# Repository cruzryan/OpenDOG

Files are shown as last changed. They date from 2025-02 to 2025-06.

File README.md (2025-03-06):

# OpenDOG

Low cost quadruped robot with SDK and Mujoco simulations, trained with Reinforcement Learning and fully opensource



## Features

- Fully 3D printed structure
- Mujoco simulation
- Trained using reinforcement learning
- Includes SDK to interface with the robot
- L515 custom SLAM implementation

## Authors

- Ryan Nathanael Cruz Barragan [@ryancruzb](https://www.github.com/ryancruzb)
- Mauricio Emiliano Ruiz Alamilla [@MaudorElConquistador](https://www.github.com/MaudorElConquistador)

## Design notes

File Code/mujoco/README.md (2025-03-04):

# 

Usage: python -m train.train [locomotion] --eval_frecuency m --n_envs n --seed i

python test [locomotion]

install.sh and upload_files.sh are scrpits for training in cloud, only tested with Azure

# Imporatant variables

## Access to information in mujoco

Information of the principal body: 

data.qvel = \[v_{x}, v_{y}, v_{z}, 
			\omega_{x}, \omega{y}, \omega{z},
			\dot{\theta_{1}}, \dot{\theta_{2}}, ...
			\dot{\theta_{n}} \]

data.qpos = \[x, y, z, 
			w, x, y, z,
			\theta_{1}, \theta_{2}, ...
			\theta_{n} \]

data.ncon = contacts number

mujoco._functions.mj_contactForce() this function get the force of a contact according to the order of appearance

Project structure 

1. debug_scene contains scripts that help to build the kinematic tree of the robot
2. environments contains a custom environments for each locomotion (maybe OOP inherence could help), this is the same for reward calculation.
3. wireless_communication is the viewer of python biding with a server udp and a client. For the moment it's only half-duplex communication
4. models are the neural networks trained for the specific locomotion.

├── best_model
│   └── best_model.zip
├── debug_scene
│   ├── Debug.py
│   ├── get_rotations.py
│   └── show_scene.py
├── environments
│   ├── jump_environment.py
│   ├── landing_environment.py
│   └── walk_environment.py
├── install.sh
├── logs
├── models
│   ├── jump
│   └── walk
├── our_robot
├── ppo_robot_tensorboard
├── README.md
├── rewards
│   ├── jump_environment_reward_calc.py
│   ├── landing_environment_reward_calc.py
│   └── walk_environment_reward_calc.py
├── test.py
├── train
│   ├── CurstomNetwork.py
│   ├── RobotUtilities.py
│   ├── train.py
│   └── VideoRecorder.py
├── unitree_go1/
├── upload_files.sh
├── videos
│   ├── jump
│   └── walk
├── viewer.py
└── wireless_comunication
    ├── client.py
    └── server.py

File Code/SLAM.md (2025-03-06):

# RealSense L515 SLAM with ROS Noetic on Ubuntu 20.04  

The realsense L515 camera was deprecated, and is not compatible with new librealsense updates or even realsense-viewer, this is a tutorial on how to do SLAM with the Intel L515 camera in 2025 lol

1. Install Ubuntu 20.04, downgrade kernel to 5.4 

	`sudo apt update`
 `sudo apt install linux-generic`

	Verify it’s there:

	`dpkg --list | grep linux-image`

	You should see linux-image-5.4.0-208-generic (or similar) alongside 5.15.

	`sudo reboot`

Note: When GRUB starts make sure to pick GRUB > “Advanced options” > pick 5.4 
`uname -r` should say 5.4.0-xx.

3.  Install dependencies:
    
    `sudo apt install -y git cmake libssl-dev libusb-1.0-0-dev libudev-dev pkg-config libgtk-3-dev libglfw3-dev libgl1-mesa-dev libglu1-mesa-dev`
    
4.  Clone and checkout v2.50.0:
    This is the latest realsense lib update that is compatible with L515
    `cd ~/Downloads git clone https://github.com/IntelRealSense/librealsense.git cd librealsense git checkout v2.50.0`
    
5.  Build and install (avoid libusb if on 5.4):
    
    `mkdir build && cd build cmake .. -DBUILD_EXAMPLES=true -DCMAKE_BUILD_TYPE=Release make -j4 && sudo make install`
    
    -   If USB errors (control_transfer), try `-DFORCE_RSUSB_BACKEND=true` instead, but 5.4 kernel driver worked for us.
6.  Test:
    
    `realsense-viewer`
    
## Step 3: Install ROS Noetic

Ubuntu 20.04 loves Noetic—our SLAM backbone.

1.  Setup repo:

    `sudo sh -c 'echo "deb http://packages.ros.org/ros/ubuntu focal main" > /etc/apt/sources.list.d/ros-latest.list'  sudo apt-key adv --keyserver 'hkp://keyserver.ubuntu.com:80' --recv-key C1CF6E31E6BADE8868B172B4F42ED6FBAB17C654`

	` sudo apt update`
    
2.  Install:

    `sudo apt install -y ros-noetic-desktop-full echo  "source /opt/ros/noetic/setup.bash" >> ~/.bashrc` 
    
    `source ~/.bashrc` 
    `sudo apt install -y python3-rosdep python3-rosinstall` 
    
    `sudo rosdep init rosdep update`

## Step 4: Install RealSense ROS Wrapper

Version 2.3.2 matches librealsense v2.50.0.

1.  Create workspace:
  
    `mkdir -p ~/catkin_ws/src`
    `cd ~/catkin_ws/src`
    `git clone -b 2.3.2 https://github.com/IntelRealSense/realsense-ros.git`
    
2.  Install dependency (our ddynamic_reconfigure snag):

    `sudo apt install -y ros-noetic-ddynamic-reconfigure`
    
3.  Build:

    `cd ~/catkin_ws` 
    `catkin_make source devel/setup.bash`
    `echo  "source ~/catkin_ws/devel/setup.bash" >> ~/.bashrc`

## Step 5: Install RTAB-Map

RTAB-Map’s our SLAM engine—needs core libs too.

1.  Install:
    
    `sudo apt install -y ros-noetic-rtabmap ros-noetic-rtabmap-ros`
    ` sudo ldconfig`

## Step 6: Run SLAM

Here’s the winning combo—two commands that finally worked after resolution hell.

### Command 1: Launch RealSense Camera

Set both RGB and depth to 640x480 (4:3 aspect ratio) to avoid rgbd_odometry crashes:

`roslaunch realsense2_camera rs_camera.launch \ enable_pointcloud:=true \ enable_color:=true \ enable_depth:=true \ color_width:=640 \ color_height:=480 \ color_fps:=30 \ depth_width:=640 \ depth_height:=480 \ depth_fps:=30`

-   Terminal 1—keep it running.

### Command 2: Launch RTAB-Map SLAM

Hook RTAB-Map to the camera:

`roslaunch rtabmap_ros rtabmap.launch \ rgb_topic:=/camera/color/image_raw \ depth_topic:=/camera/depth/image_rect_raw \ camera_info_topic:=/camera/color/camera_info \ args:="-d" \ rviz:=true \ rtabmapviz:=false`

-   Terminal 2—fires up SLAM and RViz.

## RViz Setup

-   **Fixed Frame**: camera_link
-   **Displays**:
    -   Map > /rtabmap/cloud_map (the SLAM map)
    -   Image > /camera/color/image_raw (RGB feed)
    -   PointCloud2 > /camera/depth/color/points (raw points)
    -   Odometry > /rtabmap/odom (pose)
-   Move the L515—map builds in real-time!

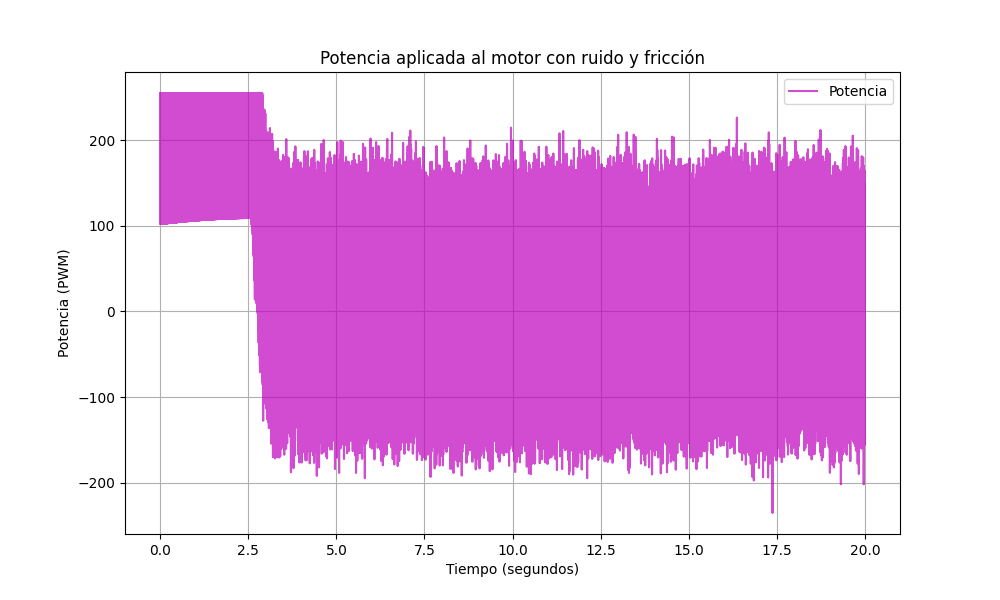
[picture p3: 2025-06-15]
Code/examples/potencia_pid.png

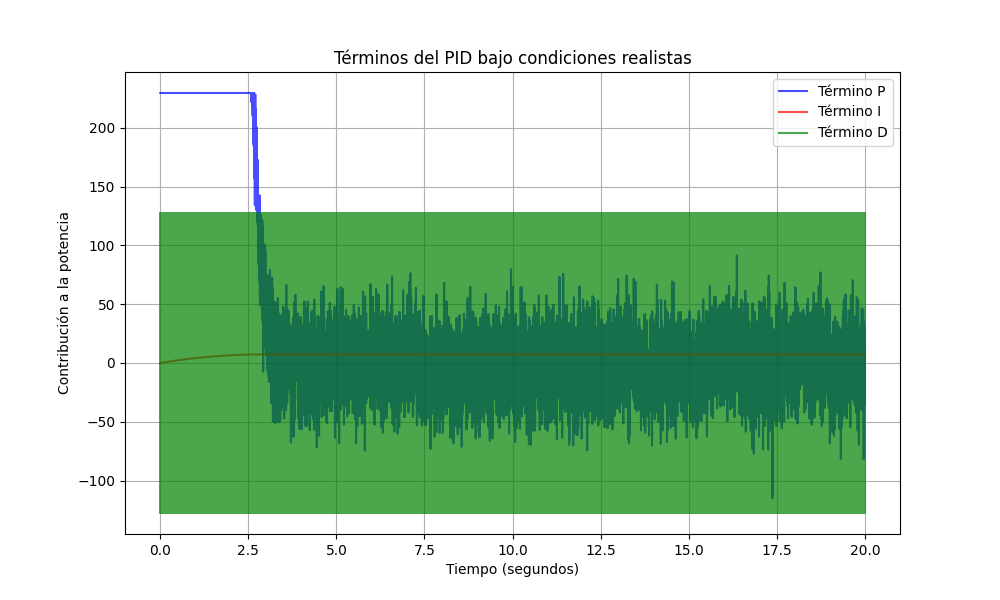
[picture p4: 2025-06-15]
Code/examples/terminos_pid.png

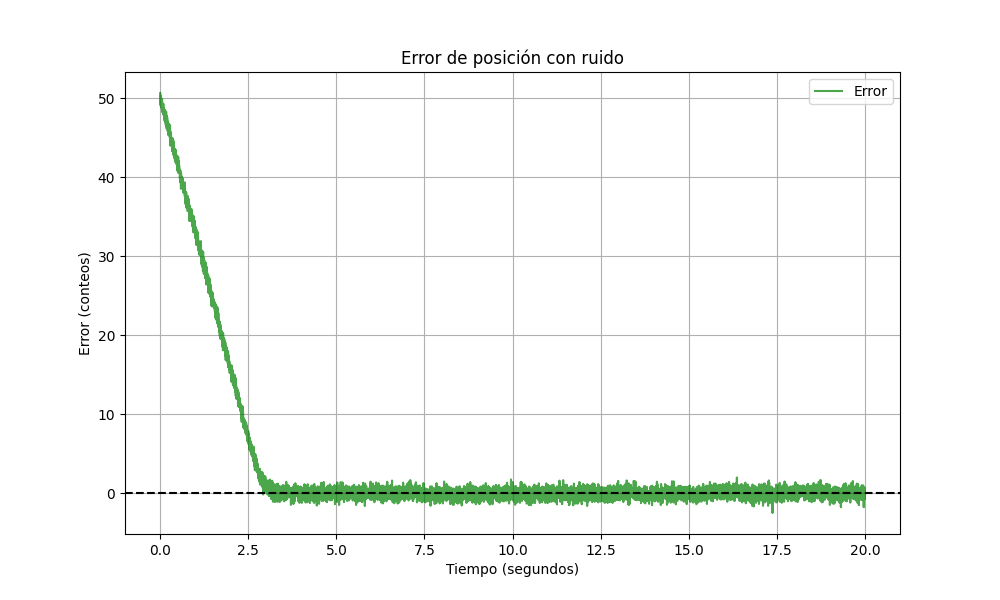
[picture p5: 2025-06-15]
Code/examples/error_pid.png

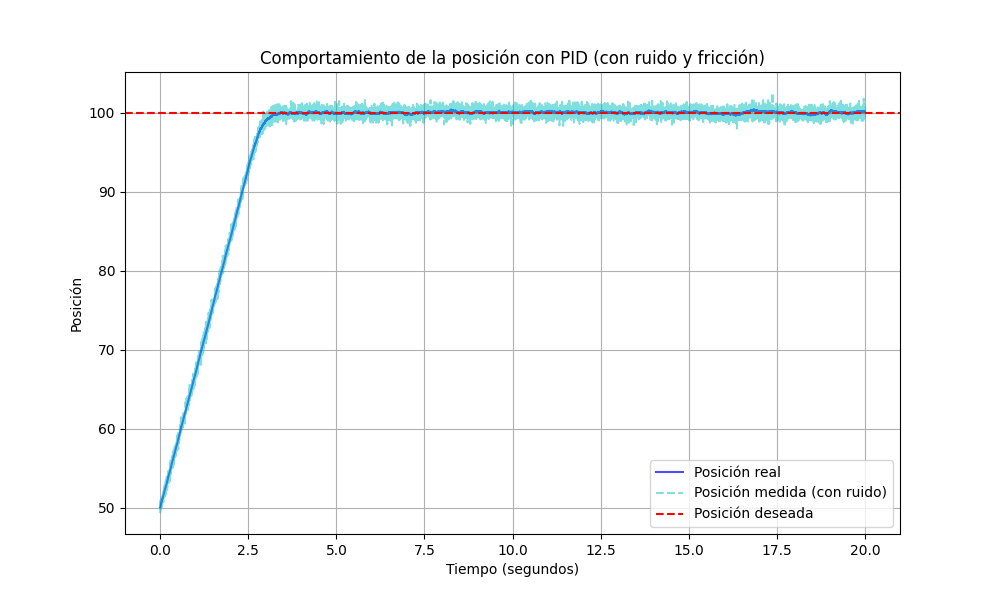
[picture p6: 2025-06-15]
Code/examples/posicion_pid.png

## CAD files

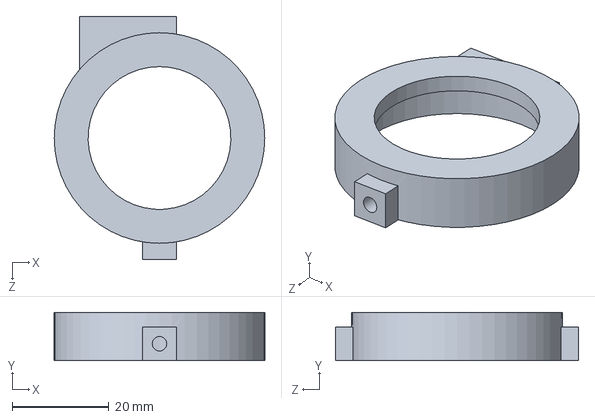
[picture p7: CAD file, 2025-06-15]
CAD/BaleroHolderTwoBBBBB.SLDPRT
43.5 x 10.0 x 50.2 mm

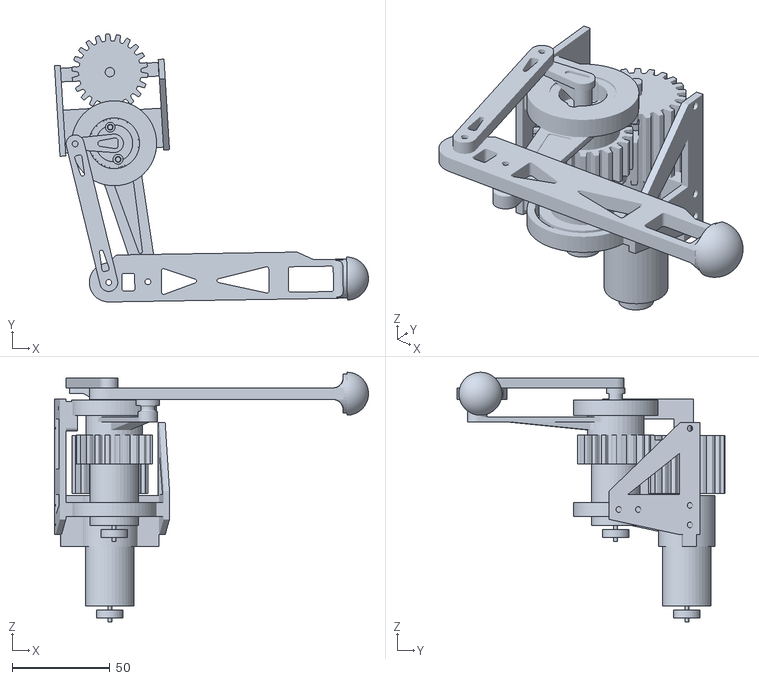
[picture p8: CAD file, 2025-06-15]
CAD/shittyleg/ShittyLeg.STL
160.8 x 137.2 x 127.8

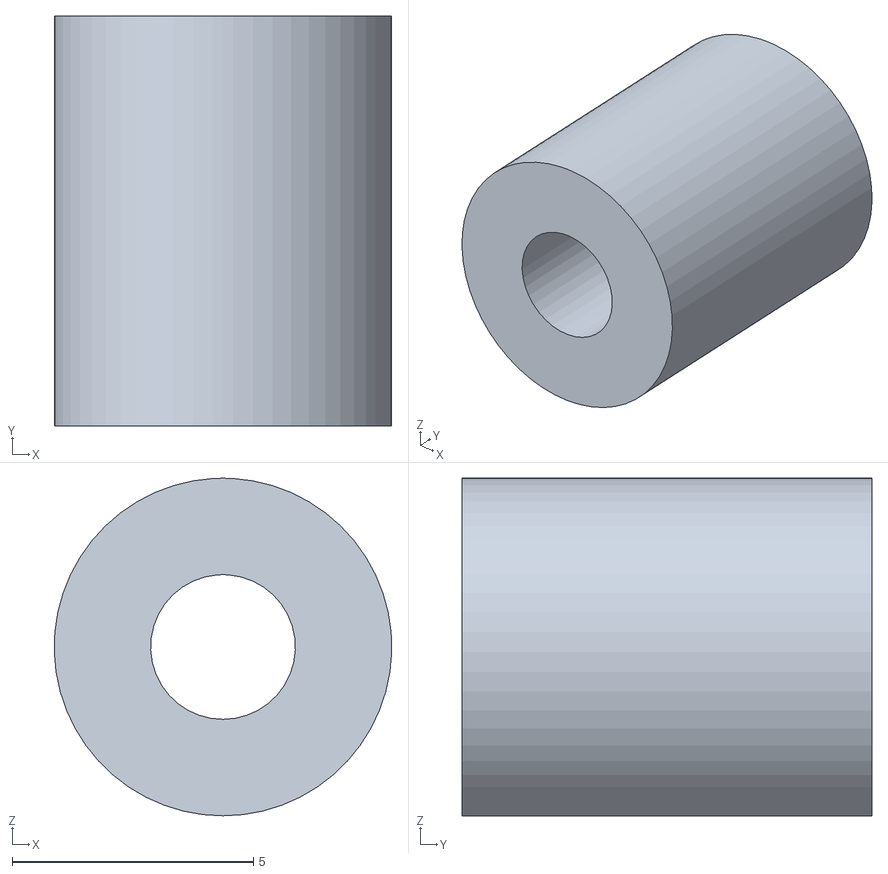
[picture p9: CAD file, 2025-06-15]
CAD/STL/b1/InterConnector.STL
7.00 x 8.50 x 7.00

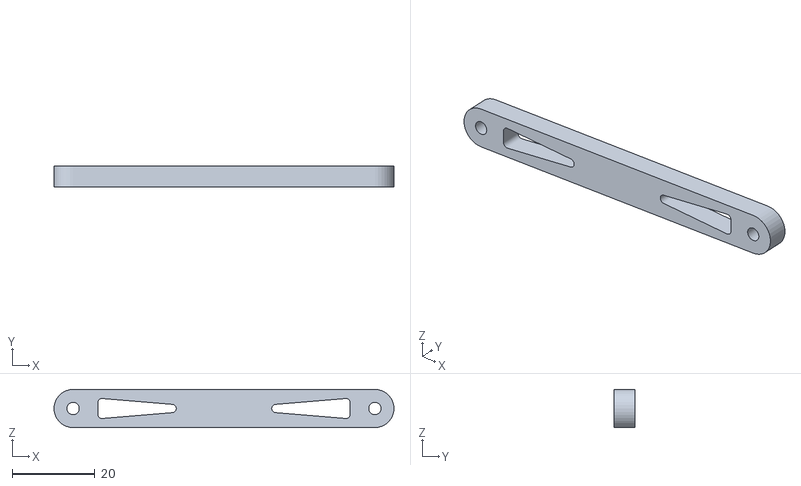
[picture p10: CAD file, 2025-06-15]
CAD/STL/b2/PartConnector.STL
82.2 x 5.00 x 9.22

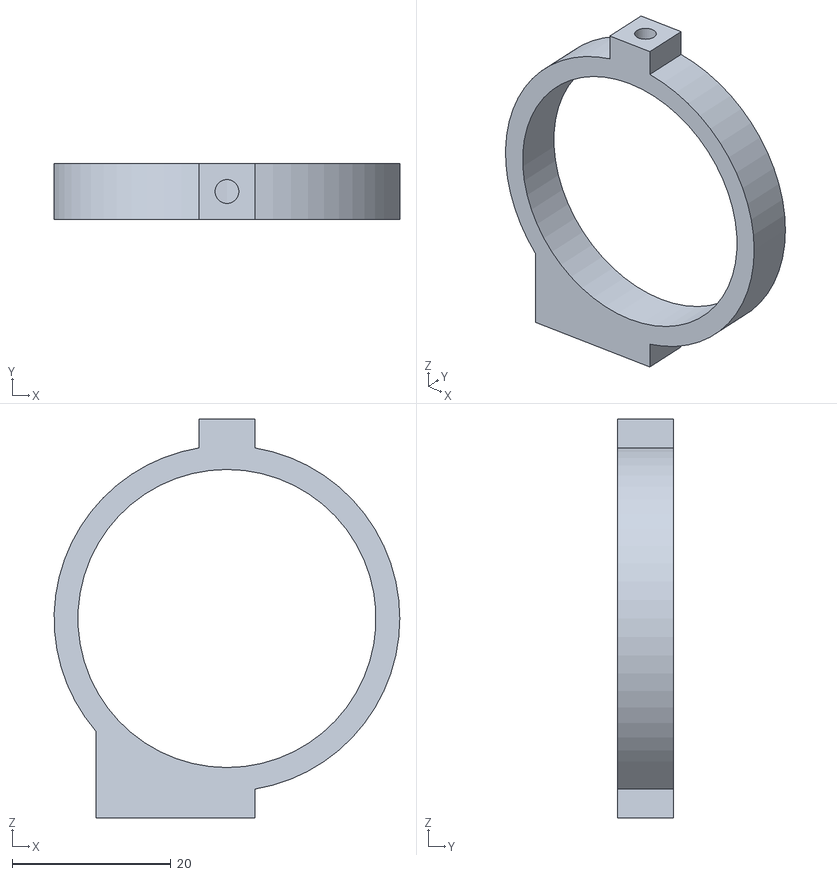
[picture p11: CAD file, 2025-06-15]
CAD/STL/b3/BaleroHolderTwo.STL
43.5 x 7.00 x 50.2

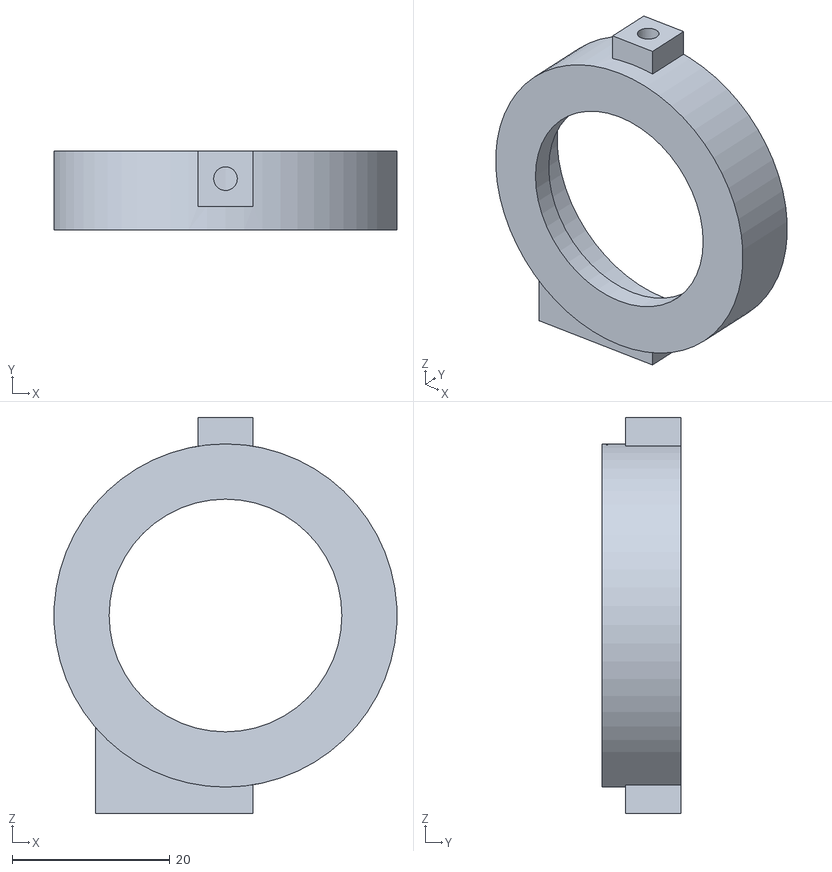
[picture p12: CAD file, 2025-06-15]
CAD/STL/BaleroHolderTwoAAAAAAAAAAAA.STL
43.4 x 10.0 x 50.2

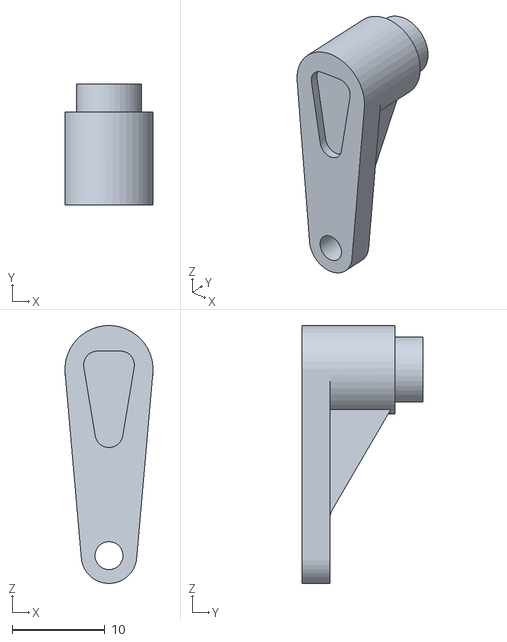
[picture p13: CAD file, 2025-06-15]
CAD/STL/FINAL/E.STL
9.50 x 13.0 x 27.8

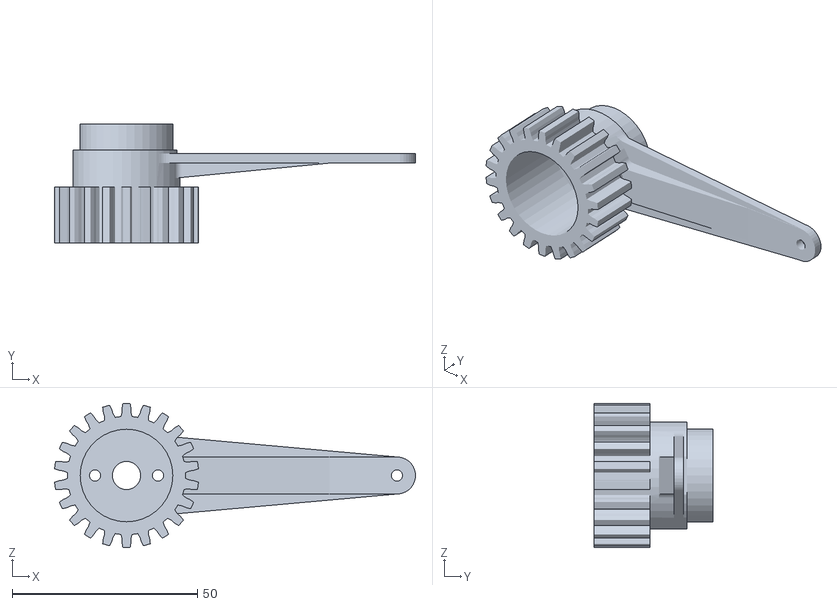
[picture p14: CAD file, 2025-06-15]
CAD/STL/FULL/C.STL
97.4 x 32.0 x 39.0

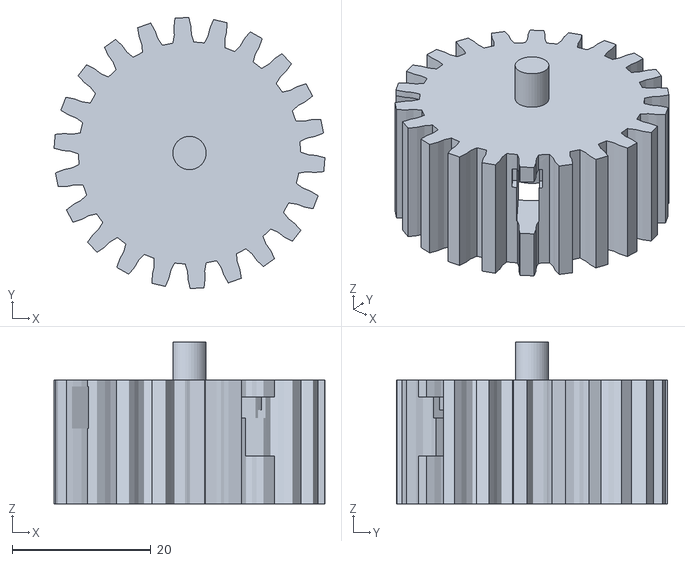
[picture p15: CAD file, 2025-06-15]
CAD/STL/LEG/ShittyLeg - engrane2cut-1.STL
39.0 x 39.1 x 23.3

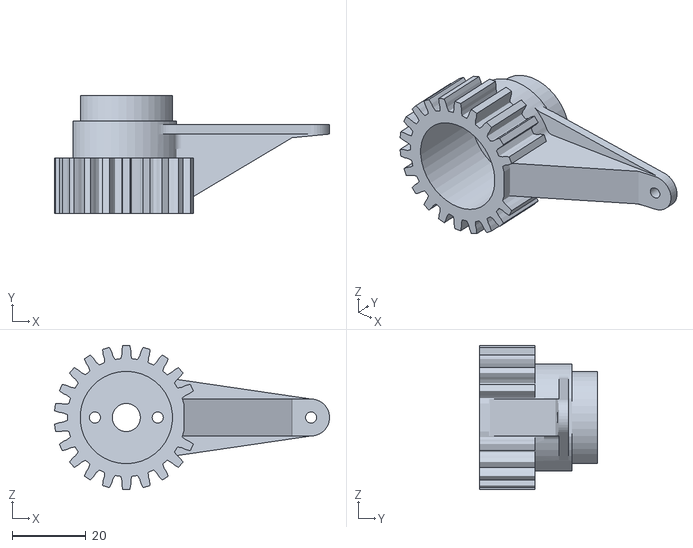
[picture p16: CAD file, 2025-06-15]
Code/mujoco/our_robot/assets/left_tigh.stl
74.4 x 32.0 x 39.0

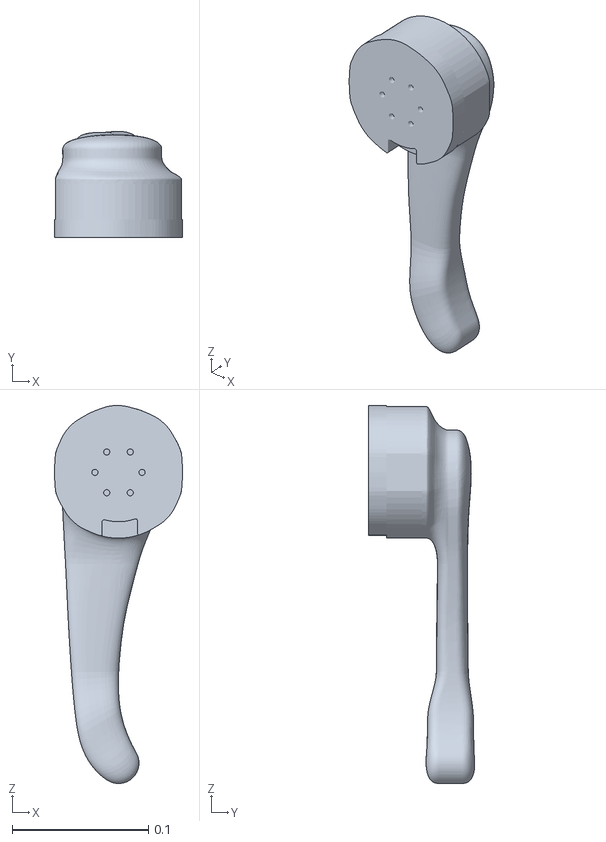
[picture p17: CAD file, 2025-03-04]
Code/mujoco/unitree_go1/assets/thigh.stl
0.094 x 0.0779 x 0.277

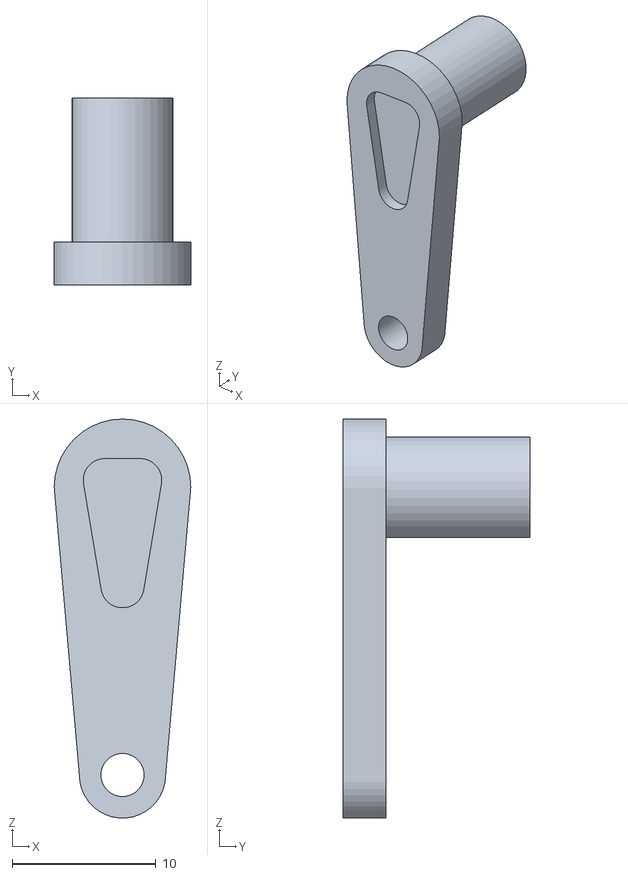
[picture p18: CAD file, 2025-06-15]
CAD/STL/b1/MotorCopler.STL
9.50 x 13.0 x 27.7

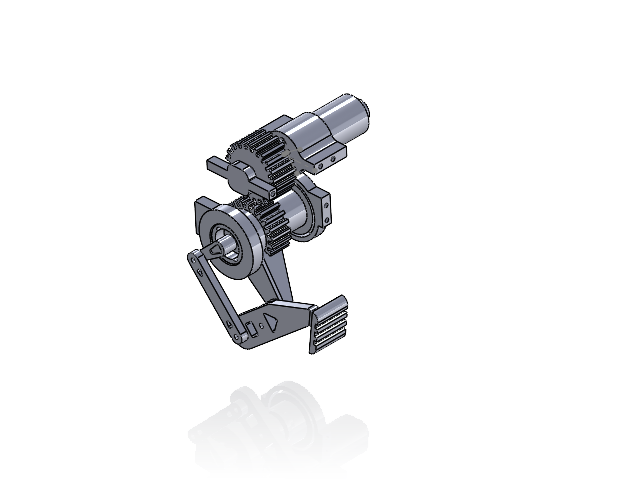
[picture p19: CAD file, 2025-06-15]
CAD/ShittyLeg.SLDASM
Motor GM25 V1 x 2
MotorCoverV5
Balero25mmv5 x 2
MotorCopler
PartConnector
InterConnector
MotorCover2
engrane2cut
BaleroHolder
BaleroHolderTwo
Balero6mmHolder
FeetLigamentSMOL45DEGREE

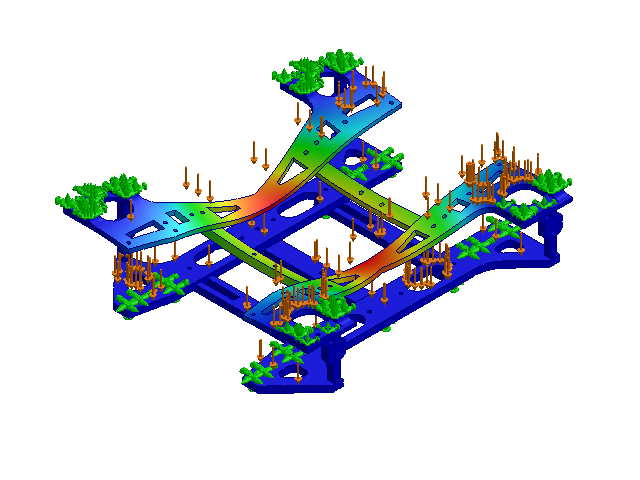
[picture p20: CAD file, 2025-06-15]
CAD/ChassiAsm.SLDASM
TopLegConnector
TopLegConnectorOTHASIDE
BonesTop x 2
BottomLegConnector x 2
Balero6mmHolder x 4
Bones x 2
BonesMiddleBottom

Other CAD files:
CAD/MirrorShittyLeg.SLDASM
CAD/STL/MUJOCO/D.STL
CAD/Balero25mmv5.SLDPRT
CAD/Balero6mmHolder.SLDPRT
CAD/BaleroHolder.SLDPRT
CAD/BaleroHolderTwo.SLDPRT
CAD/Bones.SLDPRT
CAD/Bones.STL
CAD/BonesMiddleBottom.SLDPRT
CAD/BonesTop.SLDPRT
CAD/BottomConnectorLeg3.SLDPRT
CAD/BottomLegConnector.SLDPRT
CAD/Escudo-poli.SLDPRT
CAD/FeetLigament.SLDPRT
CAD/FeetLigamentSMOL.SLDPRT
CAD/FeetLigamentSMOL45DEGREE.SLDPRT
CAD/FeetLigamentSMOL45DEGREE.STL
CAD/Floor.SLDPRT
CAD/Foot.SLDPRT
CAD/InterConnector.SLDPRT
CAD/MPU6050 v2.step
CAD/MirrorBalero25mmv5.SLDPRT
CAD/MirrorBaleroHolder.SLDPRT
CAD/MirrorBaleroHolderTwo.SLDPRT
CAD/MirrorBottomConnectorLeg3.SLDPRT
CAD/MirrorFeetLigament.SLDPRT
CAD/MirrorFoot.SLDPRT
CAD/MirrorInterConnector.SLDPRT
CAD/MirrorLelBalero25mmv5.SLDPRT
CAD/MirrorLelBaleroHolder.SLDPRT
CAD/MirrorLelBaleroHolderTwo.SLDPRT
CAD/MirrorLelBottomConnectorLeg3.SLDPRT
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

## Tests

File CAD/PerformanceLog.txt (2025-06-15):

Number of Contacts: 17
Number of contact data: 10995

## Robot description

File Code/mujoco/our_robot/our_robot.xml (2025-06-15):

<mujoco model="robot_leg">
	<compiler angle="radian" meshdir="assets" autolimits="true"/>
	<option cone="elliptic" impratio="100"/>
	<option gravity="0 0 -9.81"/>

	<default>
		<geom type="mesh" xyaxes="1 0 0 0 1 0"/>
		<default class="our_robot">
			<geom friction="0.6" margin="0.001" condim="1"/>
			<joint armature="0.02" frictionloss="0.1"/>
			<position kp="25" kv="1" forcerange="-0.83 0.83"/>
			
			<default class="tigh">
				<joint type="hinge" range="2.36 2.8" axis="0 1 0"/>
				<position ctrlrange="2.36 2.8"/>
			</default>

			<default class="knee">
				<joint type="hinge" range="-1.8 -1.20" axis="0 1 0"/>
				<position ctrlrange="-1.8 -1.20"/>
			</default>
			
			<default class="paw">
				<geom mass=".001" friction=".516 .141 .01"/>

			</default>

		</default>
	</default>

	<asset>
		<material name="dark" rgba="90 7 0.1 1"/>
		<mesh name="rigth_calf_mesh" file="rigth_calf.stl" scale=".0008 .0008 .0008" />
		<mesh name="left_calf_mesh" file="left_calf.stl" scale=".0008 .0008 .0008" />
		<mesh name="left_tigh" file="left_tigh.stl" scale=".0008 .0008 .0008" />
		<mesh name="right_tigh" file="right_tigh.stl" scale=".0008 .0008 .0008" />
		<mesh name="paw" file="paw.stl" scale=".0008 .0008 .0008"/>   
		<mesh name="chasis" file="chasis.stl" scale=".0008 .0008 .0008" />
	</asset>

	<worldbody>

		<body name="trunk" childclass="our_robot" pos="0 0 .15">
				<camera name="tracking" mode="trackcom" pos="0 -1 0.8" xyaxes="1 0 0 0 1 1"/>
				<geom contype="0" conaffinity="0" mesh="chasis" mass="1.858"/>
				<joint type="free"/>

				<body name="FL_tigh" pos="7.05e-02 8.16e-02 -13.00e-04">
						<geom mesh="left_tigh" mass=".01377"/>
						<joint class="tigh" name="FL_tigh_joint" pos="-5.00e-03 0.00e+00 0.00e-04"/>
						<body name="FL_calf" pos="3.76e-02 9.60e-03 -0.80e-03">
								<geom mesh="left_calf_mesh" mass=".01036"/>
								<joint class="knee" name="FL_knee_joint" pos="-2.40e-03 0.00e+00 8.00e-04"/>
								<body name="FL_paw" pos="4.16e-02 4.00e-03 -9.60e-03" quat="0 -0.38268343 0 0.92387953">
										<geom mesh="paw" class="paw"/>
								</body>
						</body>
				</body>

				<body name="FR_tigh" pos="7.05e-02 -7.90e-02 -13.00e-04">
						<geom mesh="right_tigh" mass=".01377"/>
						<joint class="tigh" name="FR_tigh_joint" pos="-5.00e-03 0.00e+00 0.00e-04"/>
						<body name="FR_calf" pos="3.76e-02 -9.90e-03 -0.80e-03">
								<geom mesh="rigth_calf_mesh" mass=".01036"/>
								<joint class="knee" name="FR_knee_joint" pos="-2.40e-03 0.00e+00 8.00e-04"/>
								<body name="FR_paw" pos="4.16e-02 -7.60e-03 -9.60e-03" quat="0 -0.38268343 0 0.92387953">
										<geom mesh="paw" class="paw"/>
								</body>
						</body>
				</body>
		
				<body name="BL_tigh" pos="-9.45e-02 8.16e-02 5.00e-04">
						<geom mesh="left_tigh" mass=".01377"/>
						<joint class="tigh" name="BL_tigh_joint" pos="-5.00e-03 0.00e+00 0.00e-04"/>
						<body name="BL_calf" pos="3.76e-02 9.60e-03 -0.80e-03">
								<geom mesh="left_calf_mesh" mass=".01036"/>
								<joint class="knee" name="BL_knee_joint" pos="-2.40e-03 0.00e+00 8.00e-04"/>
								<body name="BL_paw" pos="4.16e-02 -7.60e-03 -9.60e-03" quat="0 -0.38268343 0 0.92387953">
										<geom mesh="paw" class="paw"/>
								</body>
						</body>
				</body>

				<body name="BR_tigh" pos="-9.45e-02 -7.90e-02 5.00e-04">
						<geom mesh="right_tigh" mass=".01377"/>
						<joint class="tigh" name="BR_tigh_joint" pos="-5.00e-03 0.00e+00 0.00e-04"/>
						<body name="BR_calf" pos="3.76e-02 -9.90e-03 -0.80e-03">
								<geom mesh="rigth_calf_mesh" mass=".01036"/>
								<joint class="knee" name="BR_knee_joint" pos="-2.40e-03 0.00e+00 8.00e-04"/>
								<body name="BR_paw" pos="4.16e-02 -7.60e-03 -9.60e-03" quat="0 -0.38268343 0 0.92387953">
										<geom mesh="paw" class="paw"/>
								</body>
						</body>
				</body>
		</body>

	</worldbody>

	<actuator>
			<position class="tigh" name="FR_tigh_actuator" joint="FR_tigh_joint"/>
			<position class="knee" name="FR_knee_actuator" joint="FR_knee_joint"/>
			<!---->
			<position class="tigh" name="BR_tigh_actuator" joint="BR_tigh_joint"/>
			<position class="knee" name="BR_knee_actuator" joint="BR_knee_joint"/>
			<!---->
			<position class="tigh" name="FL_tigh_actuator" joint="FL_tigh_joint"/>
			<position class="knee" name="FL_knee_actuator" joint="FL_knee_joint"/>
			<!---->
			<position class="tigh" name="BL_tigh_actuator" joint="BL_tigh_joint"/>
			<position class="knee" name="BL_knee_actuator" joint="BL_knee_joint"/>
	</actuator>

	<keyframe>
			<key name="home" qpos="0 0 .20 0 0 0 0 2.35619 -1.5708 2.35619 -1.5708 2.35619 -1.5708 2.35619 -1.5708" ctrl="2.35619 -1.5708 2.35619 -1.5708 2.35619 -1.5708 2.35619 -1.5708"/>
	</keyframe>
</mujoco>

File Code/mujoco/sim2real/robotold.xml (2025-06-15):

<mujoco model="robot_leg">
	<compiler angle="radian" meshdir="assets" autolimits="true"/>
	<option cone="elliptic" impratio="100"/>
	<option gravity="0 0 -9.81"/>

	<default>	      
		<geom type="mesh" xyaxes="1 0 0 0 1 0"/>
		<default class="our_robot">
			<geom friction="0.6" margin="0.001" condim="1"/>
			<joint damping="2" armature="0.01" frictionloss="0.2"/>
			<position kp="100" forcerange="-14.7 14.7"/>
			<default class="tigh">
				<joint range="0 3.14" axis="0 1 0"/>
				<position ctrlrange=".349 3.14"/>
			</default>
			<default class="knee">
				<joint range="-2.6816 0" axis="0 1 0"/>
				<position forcerange="-14.55 14.55" ctrlrange="-2.6816 0"/>
			</default>
			  <default class="paw">
				<geom mass=".100" priority="1" solimp="0.015 1 0.023" condim="6" friction="1.5 1.5 .01"/>
			</default>
		</default>
    </default>

	<asset>
		<material name="dark" rgba="90 7 0.1 1"/>
		<mesh name="rigth_calf_mesh" file="rigth_calf.stl" scale=".01 .01 .01" />
		<mesh name="left_calf_mesh" file="left_calf.stl" scale=".01 .01 .01" />
		<mesh name="left_tigh_mesh" file="left_tigh_mesh.stl" scale=".01 .01 .01" />
		<mesh name="rigth_tigh_mesh" file="rigth_tigh_mesh.stl" scale=".01 .01 .01" />
		<mesh name="paw" file="paw.stl" scale=".01 .01 .01"/>	
		<mesh name="chasis" file="chasis.stl" scale=".01 .01 .01" />
	</asset>

	<worldbody>
		<body name="trunk" childclass="our_robot" pos="0 0 1">
			<camera name="tracking" mode="trackcom" pos="0 -1 0.8" xyaxes="1 0 0 0 1 1"/>
			<geom contype="0" conaffinity="0" mesh="chasis" mass="1.157"/>
			<joint type="free"/>
			
			<body name="FL_tigh" pos=".92 1.02 -.01">
				<geom mesh="left_tigh_mesh" mass=".01377"/>
				<joint class="tigh" name="FL_tigh_joint" pos="-.1 0 0"/>
				<body name="FL_calf" pos=".665 .120 -.010">
					<geom mesh="left_calf_mesh" mass=".01036"/>
					<joint class="knee" name="FL_knee_joint" pos="-.03 0 .01"/>
					<body name="FL_paw" pos=".52 .05 -.12" quat="0 -0.38268343 0 0.92387953" ><!---->
						<geom mesh="paw" class="paw"/>
					</body>
				</body>
			</body>

			<body name="FR_tigh" pos=".92 -1.03 -.01">
				<geom mesh="rigth_tigh_mesh" mass=".01377"/>
				<joint class="tigh" name="FR_tigh_joint" pos="-.1 0 0"/>
				<body name="FR_calf" pos=".665 -.080 -.010">
					<geom mesh="rigth_calf_mesh" mass=".01036"/>
					<joint class="knee" name="FR_knee_joint" pos="-.03 0 .01"/>
					<body name="FR_paw" pos=".52 -.095 -.12" quat="0 -0.38268343 0 0.92387953"><!---->
						<geom mesh="paw" class="paw"/>
					</body>
				</body>
			</body>
		
			<body name="BL_tigh" pos="-1.15 1.02 0">
				<geom mesh="left_tigh_mesh" mass=".01377"/>
				<joint class="tigh" name="BL_tigh_joint" pos="-.1 0 0"/>
				<body name="BL_calf" pos=".665 .120 -.010">
					<geom mesh="left_calf_mesh" mass=".01036"/>
					<joint class="knee" name="BL_knee_joint" pos="-.03 0 .01"/>
					<body name="BL_paw" pos=".52 .05 -.12" quat="0 -0.38268343 0 0.92387953" ><!---->
						<geom mesh="paw" class="paw"/>
					</body>
				</body>
			</body>

			<body name="BR_tigh" pos="-1.15 -1.03 0">
				<geom mesh="rigth_tigh_mesh" mass=".01377"/>
				<joint class="tigh" name="BR_tigh_joint" pos="-.1 0 0"/>
				<body name="BR_calf" pos=".665 -.080 -.010">
					<geom mesh="rigth_calf_mesh" mass=".01036"/>
					<joint class="knee" name="BR_knee_joint" pos="-.03 0 .01"/>
					<body name="BR_paw" pos=".52 -.095 -.12" quat="0 -0.38268343 0 0.92387953"><!---->
						<geom mesh="paw" class="paw"/>
					</body>
				</body>
			</body>
		</body>

	</worldbody>

	<actuator>
		<position class="tigh" name="FR_tigh_actuator" joint="FR_tigh_joint"/>
		<position class="knee" name="FR_knee_actuator" joint="FR_knee_joint"/>
		<!---->
		<position class="tigh" name="BR_tigh_actuator" joint="BR_tigh_joint"/>
		<position class="knee" name="BR_knee_actuator" joint="BR_knee_joint"/>
		<!---->
		<position class="tigh" name="FL_tigh_actuator" joint="FL_tigh_joint"/>
		<position class="knee" name="FL_knee_actuator" joint="FL_knee_joint"/>
		<!---->
		<position class="tigh" name="BL_tigh_actuator" joint="BL_tigh_joint"/>
		<position class="knee" name="BL_knee_actuator" joint="BL_knee_joint"/>
	</actuator>

	<!--0 0 1.5 0 0 0 0 -->
	<keyframe>
		<!-- <key name="home" qpos="0 0 1.5 0 0 0 0 2.36619 -1.5708 2.36619 -1.5708 2.36619 -1.5708 2.36619 -1.5708" ctrl="2.35619 -1.5708 2.35619 -1.5708 2.35619 -1.5708 2.35619 -1.5708"/> -->
		<key name="home" qpos="0 0 1.0 0 0 0 0 2.94 -2.2 2.62 -1.81 2.92 -2.2 2.62 -1.88" ctrl="2.94 -2.2 2.62 -1.81 2.92 -2.2 2.62 -1.88"/>
	</keyframe>
</mujoco>

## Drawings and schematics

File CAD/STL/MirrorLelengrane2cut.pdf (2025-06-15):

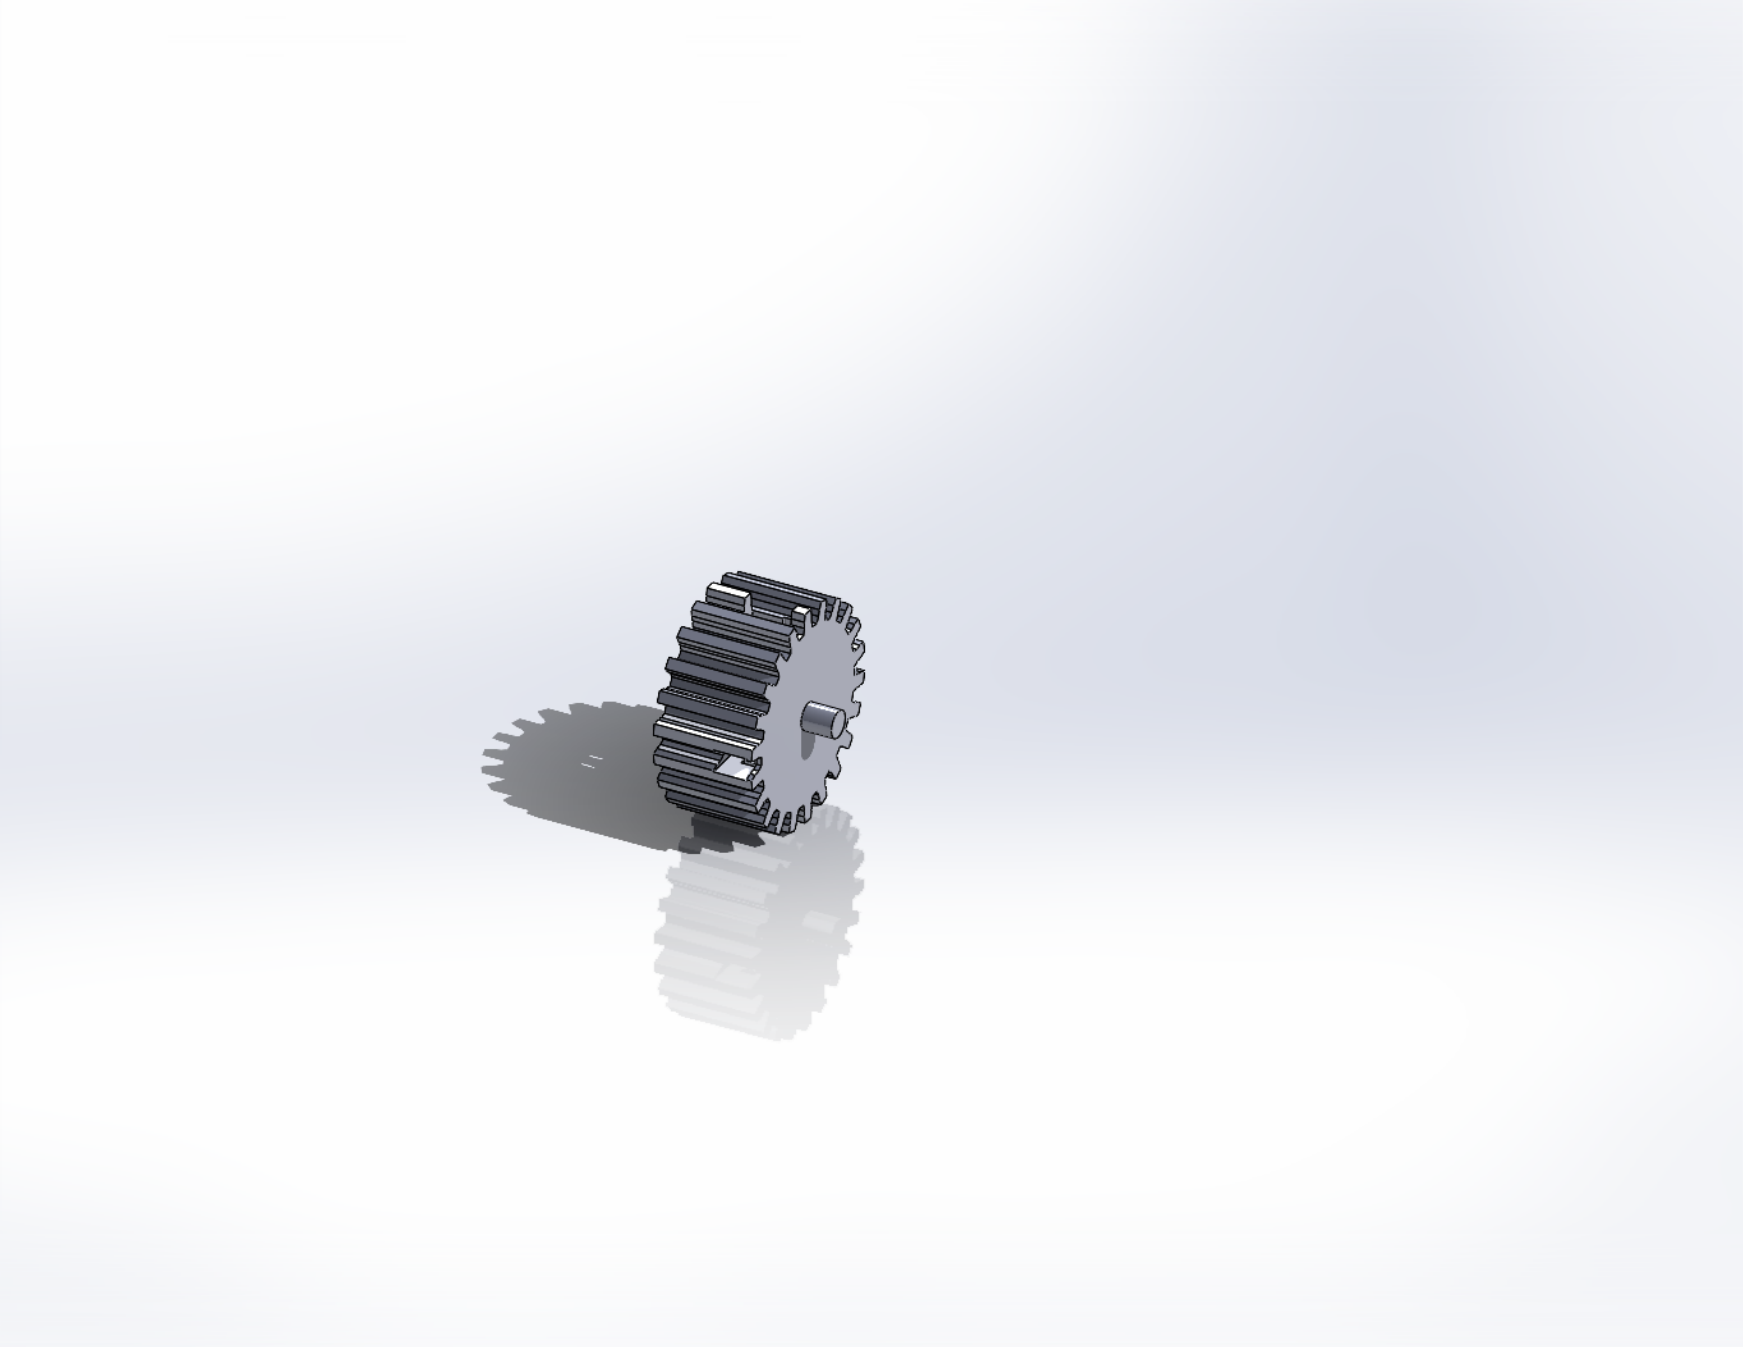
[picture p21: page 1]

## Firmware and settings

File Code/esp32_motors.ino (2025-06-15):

#include <Arduino.h>
#include <WiFi.h>
#include <WiFiUdp.h>
#include <ArduinoJson.h>
#include <Wire.h>

// MPU6050 DMP Libraries
#include "I2Cdev.h"
#include "MPU6050_6Axis_MotionApps20.h"

// WiFi credentials
#define SSID "TT"
#define PASSWORD "12345678"
#define UDP_PORT 12345

// Set static IP configuration
IPAddress local_IP(192, 168, 137, 101);
IPAddress gateway(192, 168, 137, 1);
IPAddress subnet(255, 255, 255, 0);
IPAddress primaryDNS(8, 8, 8, 8);
IPAddress secondaryDNS(8, 8, 4, 4);

const int NUM_MOTORS = 4;

float kp = 0.9;
float ki = 0.001;
float kd = 0.3;
int DEAD_ZONE = 10;
int MAX_POWER = 255;
int POSITION_THRESHOLD = 5;

const int COUNTS_PER_REV = 1975;

unsigned long lastTime = 0;
const unsigned long dt = 2;

WiFiUDP udp;
volatile bool targetPosUpdated = false;
long debugTargetPos[4] = {0, 0, 0, 0};

struct Motor {
    int ENCODER_A;
    int ENCODER_B;
    int IN1; 
    int IN2; 
    volatile long encoderPos;
    volatile long targetPos;
    long lastError;
    float integralError;
    bool controlEnabled;
    unsigned long lastAChange;
    unsigned long lastBChange;
    bool lastAState;
    bool lastBState;
};
Motor motors[NUM_MOTORS];

#define I2C_SDA 19
#define I2C_SCL 20

MPU6050 mpu;

#define EARTH_GRAVITY_MS2 9.80665
#define DEG_TO_RAD        0.017453292519943295769236907684886
#define RAD_TO_DEG        57.295779513082320876798154814105

bool dmpReady = false;
uint8_t mpuIntStatus;
uint8_t devStatus;
uint16_t packetSize;
uint8_t fifoBuffer[64];

Quaternion q_mpu; // Renamed from q to q_mpu
VectorInt16 aa_raw_fifo;      
VectorInt16 aa_linear_sensor; 
VectorInt16 aaWorld;          
VectorFloat gravity;
float ypr[3];

float currentQuaternion[4];
float currentWorldAccel[3];
float currentYPR[3];

void IRAM_ATTR handleEncoderA(void* arg) {
    Motor* motor = (Motor*)arg;
    unsigned long now = micros();
    motor->lastAChange = now;
    bool encAVal = digitalRead(motor->ENCODER_A);
    bool encBVal = digitalRead(motor->ENCODER_B);
    if (encAVal != motor->lastAState) {
        motor->lastAState = encAVal;
        if (encAVal == encBVal) {
            motor->encoderPos--;
        } else {
            motor->encoderPos++;
        }
    }
}

void IRAM_ATTR handleEncoderB(void* arg) {
    Motor* motor = (Motor*)arg;
    unsigned long now = micros();
    if (now - motor->lastBChange < 1000) return; // FIX THISSSSSSSSSSSSSSSSSSSSSSSSSSSSSSSSSSSSSSSSSSSSSSSSSSSSSSSSSSSSSSSSSSSSSSSSSSSSSSSSSS
    motor->lastBChange = now;
    bool encAVal = digitalRead(motor->ENCODER_A);
    bool encBVal = digitalRead(motor->ENCODER_B);
    if (encBVal != motor->lastBState) {
        motor->lastBState = encBVal;
        if (encAVal == encBVal) {
            motor->encoderPos++;
        } else {
            motor->encoderPos--;
        }
    }
}

void setMotor(int motorIndex, int power) {
    Motor &motor = motors[motorIndex];
    if (power == 0) {
        ledcWrite(motor.IN1, 255); 
        ledcWrite(motor.IN2, 255); 
    } else if (power > 0) {
        ledcWrite(motor.IN2, 0);
        ledcWrite(motor.IN1, power);
    } else {
        ledcWrite(motor.IN1, 0);
        ledcWrite(motor.IN2, -power);
    }
}

int computePower(long error, long errorDelta) {
    if (abs(error) <= DEAD_ZONE) {
        return 0;
    }
    float scaled_error = constrain((float)error / POSITION_THRESHOLD, -1.0, 1.0);
    float dt_sec = dt / 1000.0;
    float p_term = kp * scaled_error * MAX_POWER;
    float d_term = kd * (errorDelta / dt_sec);
    if (abs(error) <= DEAD_ZONE * 5) {
        d_term *= 3.0;
    }
    int power = p_term + constrain(d_term, -MAX_POWER / 2, MAX_POWER / 2);
    return constrain(power, -MAX_POWER, MAX_POWER);
}

void controlMotor(int motorIndex) {
    Motor &motor = motors[motorIndex];
    if (!motor.controlEnabled) {
        setMotor(motorIndex, 0);
        return;
    }
    long error = motor.targetPos - motor.encoderPos;
    long errorDelta = error - motor.lastError;
    motor.lastError = error;
    if (ki != 0 && abs(error) < MAX_POWER / abs(ki)) { // Check ki is not zero and use abs(ki)
        motor.integralError += error * (dt / 1000.0);
    } else if (ki != 0) {
        motor.integralError = constrain(motor.integralError, -MAX_POWER / abs(ki), MAX_POWER / abs(ki));
    } else {
        motor.integralError = 0;
    }
    int power = computePower(error, errorDelta) + ki * motor.integralError;
    setMotor(motorIndex, power);
}

void handle_set_control_params(const JsonDocument& doc) {
    if (doc.containsKey("P")) kp = doc["P"].as<float>();
    if (doc.containsKey("I")) ki = doc["I"].as<float>();
    if (doc.containsKey("D")) kd = doc["D"].as<float>();
    if (doc.containsKey("dead_zone")) DEAD_ZONE = doc["dead_zone"].as<int>();
    if (doc.containsKey("pos_thresh")) POSITION_THRESHOLD = doc["pos_thresh"].as<int>();
}

void handle_set_angles(int angles[], size_t arraySize) {
    for (size_t i = 0; i < arraySize && i < NUM_MOTORS; i++) {
        int angleDeg = angles[i];
        long computedTargetPos = static_cast<long>(angleDeg * static_cast<float>(COUNTS_PER_REV) / 360.0);
        motors[i].targetPos = computedTargetPos;
        debugTargetPos[i] = computedTargetPos;
    }
    targetPosUpdated = true;
}

void handle_set_all_pins(const JsonDocument& doc) {
    for (int i = 0; i < NUM_MOTORS; i++) {
        Motor &motor = motors[i];
        int new_ENCODER_A = motor.ENCODER_A;
        int new_ENCODER_B = motor.ENCODER_B;
        int new_IN1 = motor.IN1;
        int new_IN2 = motor.IN2;
        char key[12];
        snprintf(key, sizeof(key), "ENCODER_A%d", i);
        if (doc.containsKey(key)) new_ENCODER_A = doc[key].as<int>();
        snprintf(key, sizeof(key), "ENCODER_B%d", i);
        if (doc.containsKey(key)) new_ENCODER_B = doc[key].as<int>();
        snprintf(key, sizeof(key), "IN1_%d", i);
        if (doc.containsKey(key)) new_IN1 = doc[key].as<int>();
        snprintf(key, sizeof(key), "IN2_%d", i);
        if (doc.containsKey(key)) new_IN2 = doc[key].as<int>();

        if (motor.ENCODER_A != -1 && digitalPinToInterrupt(motor.ENCODER_A) != NOT_AN_INTERRUPT) detachInterrupt(digitalPinToInterrupt(motor.ENCODER_A));
        if (motor.ENCODER_B != -1 && digitalPinToInterrupt(motor.ENCODER_B) != NOT_AN_INTERRUPT) detachInterrupt(digitalPinToInterrupt(motor.ENCODER_B));
        
        motor.ENCODER_A = new_ENCODER_A;
        motor.ENCODER_B = new_ENCODER_B;
        motor.IN1 = new_IN1; 
        motor.IN2 = new_IN2; 

        if (motor.ENCODER_A != -1) {
            pinMode(motor.ENCODER_A, INPUT_PULLUP);
            if (digitalPinToInterrupt(motor.ENCODER_A) != NOT_AN_INTERRUPT) {
                attachInterruptArg(digitalPinToInterrupt(motor.ENCODER_A), handleEncoderA, &motor, CHANGE);
            }
        }
        if (motor.ENCODER_B != -1) {
            pinMode(motor.ENCODER_B, INPUT_PULLUP);
            if (digitalPinToInterrupt(motor.ENCODER_B) != NOT_AN_INTERRUPT) {
                attachInterruptArg(digitalPinToInterrupt(motor.ENCODER_B), handleEncoderB, &motor, CHANGE);
            }
        }

        if (motor.IN1 != -1) {
            pinMode(motor.IN1, OUTPUT);
            digitalWrite(motor.IN1, LOW);
            ledcAttachChannel(motor.IN1, 1000, 8, i * 2); 
            ledcWrite(motor.IN1, 255);                   
        }
        if (motor.IN2 != -1) {
            pinMode(motor.IN2, OUTPUT);
            digitalWrite(motor.IN2, LOW);
            ledcAttachChannel(motor.IN2, 1000, 8, i * 2 + 1); 
            ledcWrite(motor.IN2, 255);                       
        }
    }
}

void handle_set_control_status(const JsonDocument& doc) {
    if (doc.containsKey("motor") && doc.containsKey("status")) {
        int motorIndex = doc["motor"].as<int>();
        if (motorIndex >= 0 && motorIndex < NUM_MOTORS) {
            int status = doc["status"].as<int>();
            motors[motorIndex].controlEnabled = (status != 0);
            if (motors[motorIndex].controlEnabled) {
                motors[motorIndex].targetPos = motors[motorIndex].encoderPos;
                motors[motorIndex].lastError = 0;
                motors[motorIndex].integralError = 0;
            } else {
                setMotor(motorIndex, 0);
            }
        }
    }
}

void handle_reset_all() {
    for (int i = 0; i < NUM_MOTORS; i++) {
        motors[i].encoderPos = 0;
        motors[i].targetPos = 0;
        motors[i].lastError = 0;
        motors[i].integralError = 0;
        debugTargetPos[i] = 0;
    }
}

void handle_get_imu_data(IPAddress senderIP, int senderPort) {
    StaticJsonDocument<512> doc;
    if (dmpReady) {
        JsonObject imu_data = doc.createNestedObject("dmp_data");
        JsonObject quat_data = imu_data.createNestedObject("quaternion");
        quat_data["w"] = currentQuaternion[0];
        quat_data["x"] = currentQuaternion[1];
        quat_data["y"] = currentQuaternion[2];
        quat_data["z"] = currentQuaternion[3];
        JsonObject accel_world_data = imu_data.createNestedObject("world_accel_mps2");
        accel_world_data["ax"] = currentWorldAccel[0];
        accel_world_data["ay"] = currentWorldAccel[1];
        accel_world_data["az"] = currentWorldAccel[2];
        JsonObject ypr_data = imu_data.createNestedObject("ypr_deg");
        ypr_data["yaw"] = currentYPR[0];
        ypr_data["pitch"] = currentYPR[1];
        ypr_data["roll"] = currentYPR[2];
        doc["dmp_status"] = "ready";
    } else {
        doc["dmp_status"] = "not_ready";
        doc["error"] = "MPU6050 DMP not initialized or error";
    }
    char json[512];
    size_t len = serializeJson(doc, json);
    udp.beginPacket(senderIP, senderPort);
    udp.write((uint8_t*)json, len);
    udp.endPacket();
}

// Helper function for manual quaternion rotation
void rotateVectorByQuaternion(VectorInt16* v_sensor, Quaternion* q_rot, VectorInt16* v_world) {
    float vx = v_sensor->x;
    float vy = v_sensor->y;
    float vz = v_sensor->z;

    float qw = q_rot->w;
    float qx = q_rot->x;
    float qy = q_rot->y;
    float qz = q_rot->z;

    // Pre-calculate products for efficiency
    float _2qx = 2.0f * qx;
    float _2qy = 2.0f * qy;
    float _2qz = 2.0f * qz;
    // float _2qw = 2.0f * qw; // Not directly used in this form of the matrix

    float _2qwqx = _2qx * qw; // 2qwqx
    float _2qwqy = _2qy * qw; // 2qwqy
    float _2qwqz = _2qz * qw; // 2qwqz
    float _2qxqy = _2qx * qy; // 2qxqy
    float _2qxqz = _2qx * qz; // 2qxqz
    float _2qyqz = _2qy * qz; // 2qyqz
    
    float qx_sq = qx * qx;
    float qy_sq = qy * qy;
    float qz_sq = qz * qz;
    // float qw_sq = qw * qw; // Not directly used in this form of the matrix

    // Rotation matrix elements
    // Rxx = 1 - 2*qy^2 - 2*qz^2  (qw^2 + qx^2 - qy^2 - qz^2 if normalized)
    // Rxy = 2*qx*qy - 2*qw*qz
    // Rxz = 2*qx*qz + 2*qw*qy
    // Ryx = 2*qx*qy + 2*qw*qz
    // Ryy = 1 - 2*qx^2 - 2*qz^2  (qw^2 - qx^2 + qy^2 - qz^2 if normalized)
    // Ryz = 2*qy*qz - 2*qw*qx
    // Rzx = 2*qx*qz - 2*qw*qy
    // Rzy = 2*qy*qz + 2*qw*qx
    // Rzz = 1 - 2*qx^2 - 2*qy^2  (qw^2 - qx^2 - qy^2 + qz^2 if normalized)

    // Assuming q is a unit quaternion (qw^2 + qx^2 + qy^2 + qz^2 = 1)
    // If not, it should be normalized before this function.
    // The DMP output quaternion should be a unit quaternion.

    v_world->x = vx * (1.0f - 2.0f*qy_sq - 2.0f*qz_sq) + vy * (_2qxqy - _2qwqz)         + vz * (_2qxqz + _2qwqy);
    v_world->y = vx * (_2qxqy + _2qwqz)         + vy * (1.0f - 2.0f*qx_sq - 2.0f*qz_sq) + vz * (_2qyqz - _2qwqx);
    v_world->z = vx * (_2qxqz - _2qwqy)         + vy * (_2qyqz + _2qwqx)         + vz * (1.0f - 2.0f*qx_sq - 2.0f*qy_sq);
}

void updateDMPData() {
    if (!dmpReady) return;
    if (mpu.dmpGetCurrentFIFOPacket(fifoBuffer)) {
        mpu.dmpGetQuaternion(&q_mpu, fifoBuffer); 
        currentQuaternion[0] = q_mpu.w;
        currentQuaternion[1] = q_mpu.x;
        currentQuaternion[2] = q_mpu.y;
        currentQuaternion[3] = q_mpu.z;

        mpu.dmpGetGravity(&gravity, &q_mpu);
        mpu.dmpGetAccel(&aa_raw_fifo, fifoBuffer);
        mpu.dmpGetLinearAccel(&aa_linear_sensor, &aa_raw_fifo, &gravity);
        rotateVectorByQuaternion(&aa_linear_sensor, &q_mpu, &aaWorld);

        currentWorldAccel[0] = aaWorld.x * mpu.get_acce_resolution() * EARTH_GRAVITY_MS2;
        currentWorldAccel[1] = aaWorld.y * mpu.get_acce_resolution() * EARTH_GRAVITY_MS2;
        currentWorldAccel[2] = aaWorld.z * mpu.get_acce_resolution() * EARTH_GRAVITY_MS2;

        mpu.dmpGetYawPitchRoll(ypr, &q_mpu, &gravity);
        currentYPR[0] = ypr[0] * RAD_TO_DEG;
        currentYPR[1] = ypr[1] * RAD_TO_DEG;
        currentYPR[2] = ypr[2] * RAD_TO_DEG;
    }
}

void udpTask(void *pvParameters) {
    unsigned long lastSendTime = 0;
    unsigned long sendInterval = 50;
    IPAddress broadcastIP(255, 255, 255, 255);

    while (true) {
        if (WiFi.status() != WL_CONNECTED) {
            WiFi.disconnect(true, true);
            WiFi.mode(WIFI_STA);
            WiFi.config(local_IP, gateway, subnet, primaryDNS, secondaryDNS);
            WiFi.begin(SSID, PASSWORD);
            while (WiFi.status() != WL_CONNECTED) {
                vTaskDelay(500 / portTICK_PERIOD_MS);
            }
            udp.begin(UDP_PORT);
        }

        int packetSizeUDP = udp.parsePacket();
        if (packetSizeUDP) {
            char packetBuffer[1024];
            int len = udp.read(packetBuffer, sizeof(packetBuffer) - 1);
            packetBuffer[len] = 0;
            StaticJsonDocument<1024> doc;
            DeserializationError error = deserializeJson(doc, packetBuffer);
            if (!error && doc.containsKey("command")) {
                String command = doc["command"].as<String>();
                IPAddress senderIP = udp.remoteIP();
                int senderPort = udp.remotePort();
                if (command == "set_control_params") {
                    handle_set_control_params(doc);
                } else if (command == "set_angles") {
                    if (doc.containsKey("angles") && doc["angles"].is<JsonArray>()) {
                        size_t arraySize = doc["angles"].size();
                        int tempAngles[NUM_MOTORS]; 
                        for (size_t i = 0; i < arraySize && i < NUM_MOTORS; i++) {
                            tempAngles[i] = static_cast<int>(doc["angles"][i].as<float>());
                        }
                        handle_set_angles(tempAngles, arraySize);
                    }
                } else if (command == "set_all_pins") {
                    handle_set_all_pins(doc);
                } else if (command == "set_control_status") {
                    handle_set_control_status(doc);
                } else if (command == "reset_all") {
                    handle_reset_all();
                } else if (command == "get_imu_data") {
                    handle_get_imu_data(senderIP, senderPort);
                } else if (command == "set_send_interval") {
                    if (doc.containsKey("interval") && doc["interval"].is<int>()) {
                        int newInterval = doc["interval"].as<int>();
                        if (newInterval > 0) {
                            sendInterval = newInterval;
                        }
                    }
                }
                StaticJsonDocument<64> responseDoc;
                responseDoc["status"] = "OK";
                char response[64];
                size_t responseLen = serializeJson(responseDoc, response);
                udp.beginPacket(senderIP, senderPort);
                udp.write((uint8_t*)response, responseLen);
                udp.endPacket();
                vTaskDelay(2 / portTICK_PERIOD_MS);
            }
        }

        updateDMPData();

        if (millis() - lastSendTime >= sendInterval) {
            StaticJsonDocument<1024> doc;
            JsonArray angles_json = doc.createNestedArray("angles");
            JsonArray encoderPos_arr = doc.createNestedArray("encoderPos");
            JsonArray targetPos_arr = doc.createNestedArray("targetPos");
            bool allMotorsCurrentlyEnabled = true;
            for (int i = 0; i < NUM_MOTORS; i++) {
                float angle = (float)motors[i].encoderPos * 360.0f / COUNTS_PER_REV;
                angles_json.add(angle);
                encoderPos_arr.add(motors[i].encoderPos);
                targetPos_arr.add(motors[i].targetPos);
                if (!motors[i].controlEnabled) {
                    allMotorsCurrentlyEnabled = false;
                }
            }
            doc["esp_control_fully_enabled"] = allMotorsCurrentlyEnabled;
            doc["dmp_ready"] = dmpReady;

            if (dmpReady) {
                JsonObject dmp_data_out = doc.createNestedObject("dmp_data");
                JsonObject quat_data = dmp_data_out.createNestedObject("quaternion");
                quat_data["w"] = currentQuaternion[0];
                quat_data["x"] = currentQuaternion[1];
                quat_data["y"] = currentQuaternion[2];
                quat_data["z"] = currentQuaternion[3];
                JsonObject accel_world_data = dmp_data_out.createNestedObject("world_accel_mps2");
                accel_world_data["ax"] = currentWorldAccel[0];
                accel_world_data["ay"] = currentWorldAccel[1];
                accel_world_data["az"] = currentWorldAccel[2];
                JsonObject ypr_data = dmp_data_out.createNestedObject("ypr_deg");
                ypr_data["yaw"] = currentYPR[0];
                ypr_data["pitch"] = currentYPR[1];
                ypr_data["roll"] = currentYPR[2];
            }

            char json[1024];
            size_t len = serializeJson(doc, json);
            if (len > 0 && len < sizeof(json)) {
                udp.beginPacket(broadcastIP, UDP_PORT);
                udp.write((uint8_t*)json, len);
                udp.endPacket();
            }
            lastSendTime = millis();
        }
        vTaskDelay(1 / portTICK_PERIOD_MS);
    }
}

void setup() {
    #if I2CDEV_IMPLEMENTATION == I2CDEV_ARDUINO_WIRE
        Wire.begin(I2C_SDA, I2C_SCL);
        Wire.setClock(400000);
    #elif I2CDEV_IMPLEMENTATION == I2CDEV_BUILTIN_FASTWIRE
        Fastwire::setup(400, true);
    #endif

    mpu.initialize();
    pinMode(LED_BUILTIN, OUTPUT); 

    if (mpu.testConnection()) {
        devStatus = mpu.dmpInitialize();
        mpu.setXGyroOffset(0); 
        mpu.setYGyroOffset(0);
        mpu.setZGyroOffset(0);
        mpu.setXAccelOffset(0);
        mpu.setYAccelOffset(0);
        mpu.setZAccelOffset(0);

        if (devStatus == 0) {
            mpu.CalibrateAccel(10);
            mpu.CalibrateGyro(10);
            mpu.setDMPEnabled(true);
            dmpReady = true;
            packetSize = mpu.dmpGetFIFOPacketSize();
            digitalWrite(LED_BUILTIN, HIGH); 
        } else {
            dmpReady = false; 
            digitalWrite(LED_BUILTIN, LOW); 
        }
    } else {
        dmpReady = false; 
        digitalWrite(LED_BUILTIN, LOW); 
    }

    for (int i = 0; i < NUM_MOTORS; i++) {
        motors[i].ENCODER_A = -1; motors[i].ENCODER_B = -1;
        motors[i].IN1 = -1; motors[i].IN2 = -1;
        motors[i].encoderPos = 0; motors[i].targetPos = 0;
        motors[i].lastError = 0; motors[i].integralError = 0;
        motors[i].controlEnabled = false;
        motors[i].lastAChange = 0; motors[i].lastBChange = 0;
        motors[i].lastAState = false; motors[i].lastBState = false;
    }

    WiFi.mode(WIFI_STA);
    WiFi.config(local_IP, gateway, subnet, primaryDNS, secondaryDNS);
    WiFi.begin(SSID, PASSWORD);
    while (WiFi.status() != WL_CONNECTED) {
        delay(500); 
    }
    WiFi.setSleep(false);
    
    udp.begin(UDP_PORT);

    xTaskCreatePinnedToCore( udpTask, "UDPTask", 1024 * 12, NULL, 1, NULL, 0 );
}

void loop() {
    if (millis() - lastTime >= dt) {
        for (int i = 0; i < NUM_MOTORS; i++) {
            if (motors[i].controlEnabled) {
                controlMotor(i);
            }
        }
        lastTime = millis();
    }
    vTaskDelay(1 / portTICK_PERIOD_MS);
}

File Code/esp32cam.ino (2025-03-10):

#include "esp_camera.h"
#include <WiFi.h>
#include "esp_timer.h"
#include "img_converters.h"
#include "Arduino.h"
#include "fb_gfx.h"
#include "soc/soc.h"
#include "soc/rtc_cntl_reg.h"
#include "esp_http_server.h"
#include <Adafruit_MPU6050.h>
#include <Adafruit_Sensor.h>
#include <Wire.h>
#include <ArduinoJson.h>
#include <Adafruit_ADS1X15.h>
#include <base64.h>
// Define the MIN macro
#define MIN(a, b) ((a) < (b) ? (a) : (b))

// Network credentials
const char *ssid = "TT";
const char *password = "12345678";

#define PART_BOUNDARY "123456789000000000000987654321"

// Camera model
#define CAMERA_MODEL_AI_THINKER

#if defined(CAMERA_MODEL_AI_THINKER)
  #define PWDN_GPIO_NUM     32
  #define RESET_GPIO_NUM    -1
  #define XCLK_GPIO_NUM      0
  #define SIOD_GPIO_NUM     26
  #define SIOC_GPIO_NUM     27
  #define Y9_GPIO_NUM       35
  #define Y8_GPIO_NUM       34
  #define Y7_GPIO_NUM       39
  #define Y6_GPIO_NUM       36
  #define Y5_GPIO_NUM       21
  #define Y4_GPIO_NUM       19
  #define Y3_GPIO_NUM       18
  #define Y2_GPIO_NUM        5
  #define VSYNC_GPIO_NUM    25
  #define HREF_GPIO_NUM     23
  #define PCLK_GPIO_NUM     22
#else
  #error "Camera model not selected"
#endif

static const char* _STREAM_CONTENT_TYPE = "multipart/x-mixed-replace;boundary=" PART_BOUNDARY;
static const char* _STREAM_BOUNDARY = "\r\n--" PART_BOUNDARY "\r\n";
static const char* _STREAM_PART = "Content-Type: image/jpeg\r\nContent-Length: %u\r\n\r\n";

httpd_handle_t stream_httpd = NULL;
framesize_t current_framesize = FRAMESIZE_VGA;
bool frame_size_changed = false;

// IMU Setup
#define I2C_SDA 14
#define I2C_SCL 15
Adafruit_MPU6050 mpu;

// ADS1115 Setup
Adafruit_ADS1115 ads;

// JSON Buffers
StaticJsonDocument<512> event_doc; // Larger buffer for combined data
char event_json_buffer[512];

// Stream Handler (Original)
static esp_err_t stream_handler(httpd_req_t *req) {
  camera_fb_t *fb = NULL;
  esp_err_t res = ESP_OK;
  size_t _jpg_buf_len = 0;
  uint8_t *_jpg_buf = NULL;
  char *part_buf[64];

  res = httpd_resp_set_type(req, _STREAM_CONTENT_TYPE);
  if (res != ESP_OK) return res;

  while (true) {
    if (frame_size_changed) {
      sensor_t *s = esp_camera_sensor_get();
      s->set_framesize(s, current_framesize);
      frame_size_changed = false;
    }

    fb = esp_camera_fb_get();
    if (!fb) {
      Serial.println("Camera capture failed");
      res = ESP_FAIL;
    } else {
      if (fb->format != PIXFORMAT_JPEG) {
        bool jpeg_converted = frame2jpg(fb, 80, &_jpg_buf, &_jpg_buf_len);
        esp_camera_fb_return(fb);
        fb = NULL;
        if (!jpeg_converted) {
          Serial.println("JPEG compression failed");
          res = ESP_FAIL;
        }
      } else {
        _jpg_buf_len = fb->len;
        _jpg_buf = fb->buf;
      }
    }
    if (res == ESP_OK) {
      size_t hlen = snprintf((char *)part_buf, 64, _STREAM_PART, _jpg_buf_len);
      res = httpd_resp_send_chunk(req, (const char *)part_buf, hlen);
    }
    if (res == ESP_OK) {
      res = httpd_resp_send_chunk(req, (const char *)_jpg_buf, _jpg_buf_len);
    }
    if (res == ESP_OK) {
      res = httpd_resp_send_chunk(req, _STREAM_BOUNDARY, strlen(_STREAM_BOUNDARY));
    }
    if (fb) {
      esp_camera_fb_return(fb);
      fb = NULL;
      _jpg_buf = NULL;
    } else if (_jpg_buf) {
      free(_jpg_buf);
      _jpg_buf = NULL;
    }
    if (res != ESP_OK) break;
  }
  return res;
}

// Command Handler
static esp_err_t cmd_handler(httpd_req_t *req) {
  char buf[100];
  int ret, remaining = req->content_len;

  while (remaining > 0) {
    if ((ret = httpd_req_recv(req, buf, MIN(remaining, sizeof(buf)))) <= 0) {
      if (ret == HTTPD_SOCK_ERR_TIMEOUT) continue;
      return ESP_FAIL;
    }
    buf[ret] = 0;
    String command = String(buf);
    if (command.startsWith("framesize:")) {
      String framesize_str = command.substring(10);
      Serial.println("Changing framesize to: " + framesize_str);

      if (framesize_str == "96X96") current_framesize = FRAMESIZE_96X96;
      else if (framesize_str == "QQVGA") current_framesize = FRAMESIZE_QQVGA;
      else if (framesize_str == "128X128") current_framesize = FRAMESIZE_128X128;
      else if (framesize_str == "QCIF") current_framesize = FRAMESIZE_QCIF;
      else if (framesize_str == "HQVGA") current_framesize = FRAMESIZE_HQVGA;
      else if (framesize_str == "240X240") current_framesize = FRAMESIZE_240X240;
      else if (framesize_str == "QVGA") current_framesize = FRAMESIZE_QVGA;
      else if (framesize_str == "320X320") current_framesize = FRAMESIZE_320X320;
      else if (framesize_str == "CIF") current_framesize = FRAMESIZE_CIF;
      else if (framesize_str == "HVGA") current_framesize = FRAMESIZE_HVGA;
      else if (framesize_str == "VGA") current_framesize = FRAMESIZE_VGA;
      else if (framesize_str == "SVGA") current_framesize = FRAMESIZE_SVGA;
      else if (framesize_str == "XGA") current_framesize = FRAMESIZE_XGA;
      else if (framesize_str == "HD") current_framesize = FRAMESIZE_HD;
      else if (framesize_str == "SXGA") current_framesize = FRAMESIZE_SXGA;
      else if (framesize_str == "UXGA") current_framesize = FRAMESIZE_UXGA;

      frame_size_changed = true;
      Serial.println("Frame size set to: " + framesize_str);
    }
    remaining -= ret;
  }
  httpd_resp_send(req, NULL, 0);
  return ESP_OK;
}

// IMU Data Handler (Original)
static esp_err_t imu_data_handler(httpd_req_t *req) {
  sensors_event_t a, g, temp;
  mpu.getEvent(&a, &g, &temp);

  StaticJsonDocument<200> imu_doc;
  imu_doc["accel_x"] = a.acceleration.x;
  imu_doc["accel_y"] = a.acceleration.y;
  imu_doc["accel_z"] = a.acceleration.z;
  imu_doc["gyro_x"] = g.gyro.x;
  imu_doc["gyro_y"] = g.gyro.y;
  imu_doc["gyro_z"] = g.gyro.z;
  imu_doc["temp"] = temp.temperature;

  char imu_json_buffer[200];
  serializeJson(imu_doc, imu_json_buffer);

  httpd_resp_set_type(req, "application/json");
  httpd_resp_send(req, imu_json_buffer, strlen(imu_json_buffer));
  return ESP_OK;
}

// ADS Data Handler (Original)
static esp_err_t ads_data_handler(httpd_req_t *req) {
  int16_t a0 = ads.readADC_SingleEnded(0);
  int16_t a1 = ads.readADC_SingleEnded(1);
  int16_t a2 = ads.readADC_SingleEnded(2);
  int16_t a3 = ads.readADC_SingleEnded(3);

  StaticJsonDocument<200> ads_doc;
  ads_doc["A0"] = a0;
  ads_doc["A1"] = a1;
  ads_doc["A2"] = a2;
  ads_doc["A3"] = a3;

  char ads_json_buffer[200];
  serializeJson(ads_doc, ads_json_buffer);

  httpd_resp_set_type(req, "application/json");
  httpd_resp_send(req, ads_json_buffer, strlen(ads_json_buffer));
  return ESP_OK;
}
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

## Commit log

2025-02-11 solidwork parts
    [Balero25mmv5.SLDPRT, Balero6mmHolder.SLDPRT, BaleroHolder.SLDPRT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]
2025-02-14 imu API
2025-03-03 single motor API implmented
2025-03-03 added single motor control example
2025-03-04 updated single motor controller
2025-03-04 added multi motor support API
2025-03-04 added multi motor example
2025-03-04 2 -> 8 motors for the quadruped
2025-03-04 feat: Mujoco Simulation and training added
    [calf.stl, chasis.stl, go1.xml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]
2025-03-08 feat: loop enclosure added also color
2025-03-08 feat: added pressure sensing
2025-03-17 feat: functional training for walking and force charts
    [chasis.stl, our_robot.xml]
2025-03-20 fixed pin GND initialization
    [esp32_motors.ino]
2025-03-21 found pins for each motor
2025-03-23 PWM+HW Control
2025-04-21 fixed api + 2nd esp32
    [body.py, esp32_motors.ino]
2025-04-26 fixed dual esp32 S3 implementation
    [body.py]
2025-05-03 feat: update of reward functions
    [fuerzas_patas.csv]
2025-05-04 fix: new leg added
    [left_calf.stl, our_robot.xml, paw.stl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]
2025-05-05 update: mass to 0.021
    [our_robot.xml, walking_scene.xml]
2025-05-12 feat: new size and features added
    [our_robot.xml, walking_scene.xml]
2025-05-17 switched to udp
    [our_robot.xml, walking_scene.xml]
2025-05-17 fix: camera position tracking robot
    [our_robot.xml]
2025-05-18 fix: action normalization and join ranges
    [our_robot.xml]
2025-05-21 feat: new tigh added
    [left_tigh.stl, our_robot.xml, right_tigh.stl]
2025-05-28 fix: camera record fixed
    [our_robot.xml, progress.csv]
2025-06-01 updated CAD
    [A.STL, B.STL, BALERO A.STL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]
2025-06-05 feat: walking with pattern
    [progress.csv]
2025-06-13 feat: graphics and scales action added
    [fuerzas_patas.csv]
2025-06-15 new baleroholder
    [Balero25mmv5.STL, BaleroHolderTwo.SLDPRT, BaleroHolderTwoAAAAAAAAAAAA.STL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]
